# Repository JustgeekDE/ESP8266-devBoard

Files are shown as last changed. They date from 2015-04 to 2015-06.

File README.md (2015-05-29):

# ESP 8266 Dev board
A couple of different layouts for development boards for the ESP 8266 WiFi module.

## ESP8266-dev
This board is intended as a low cost, easy to build and source entry point to ESP 8266 development. After removing (or de-populating) the ESP part of the dev board, it can also be used with a different firmware as an AVR ISP programmer, SPI interface or for a variety of other uses.

However the AVR-CDC firmware is only reliable up to 4800 baud and can't reliably negotiate the 500 mA needed for the reliable operation.

## ESP8266-dev-ftdi
This is a small badge-like breakout board with onboard RGB LEDs. The aim of this board is to provide an easy to use playground for the V-01 version of the ESP 8266 module, while still being able to be used as a general interface board.

The chip reset of the ESP8266 is only released after the 500mA has been successfully negotiated.

Since a FT230X is used, the UART interface is lacking the DTR signal.

## Errata
- The USB socket on v0.1 of the FTDI board is a bit to far away from the board edge
- The RX and TX Leds on v0.1 of the FTDI board should be tied to VCC instead of GND

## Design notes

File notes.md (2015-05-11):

- Uart to slow
- multiple connections for IO
- ISP default powered
- Reverse uart
- Check current draw on power

check IO

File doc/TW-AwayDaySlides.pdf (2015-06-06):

EU AWAY DAY 2015

# IOT AND THE ESP8266

Building your own thing of the internet in 45 minutes

## raspberry pi arduino spark.io zigBee light blue bean

… ?

## THE ESP8266

## Lots of processing power • raspberry pi • beaglebone

## Connected anywhere • particle electron

Very low power •light blue bean •JeeNode

Easy to start • particle core • particle photon

## THE ESP8266

## Network

- 802.11 b / g / n
- built-in TCP / IP stack

## CPU

- 32 bit
- 80 MHz
- 64 KB instruction RAM
- 96 KB data RAM
- 64KB boot ROM

## Input / Output

- 2-11 GPIO
- ADC / SPI / PWM / SDIO / UART / I2C

# Let’s build something

( http://esp8266.ru/esplorer/#download )

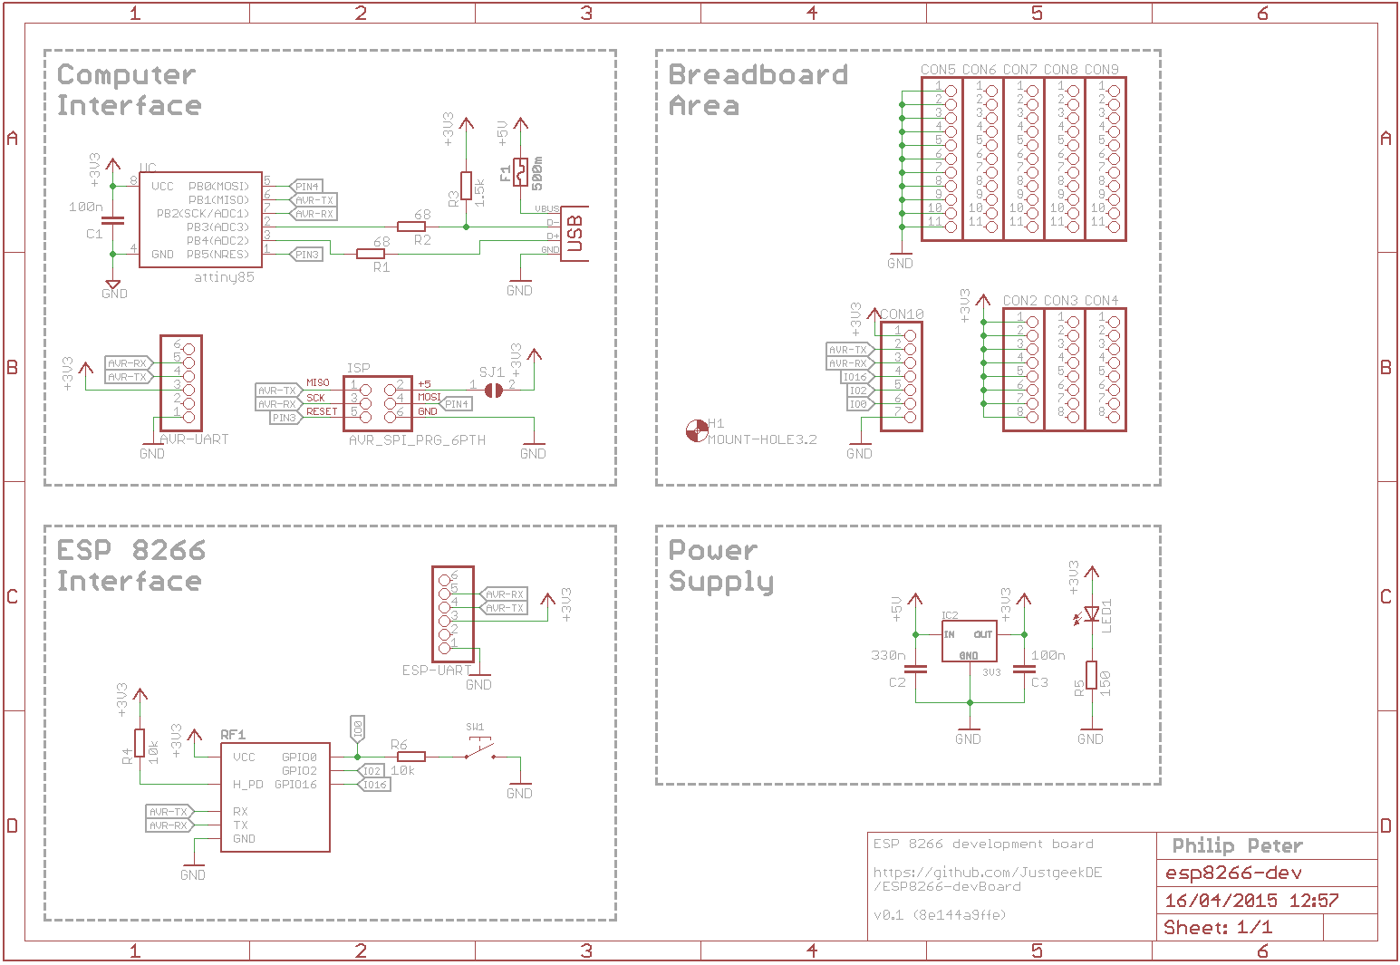
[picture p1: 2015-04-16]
doc/esp8266-dev-schematic.png

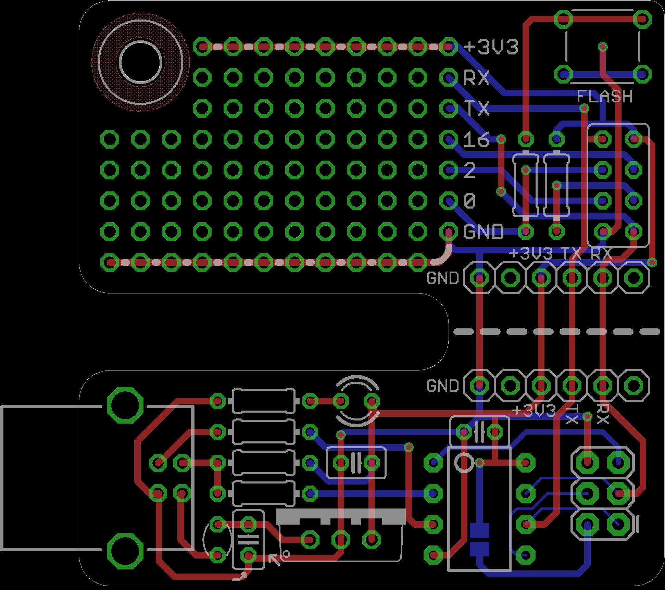
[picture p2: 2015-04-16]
doc/esp8266-dev-board-both.png

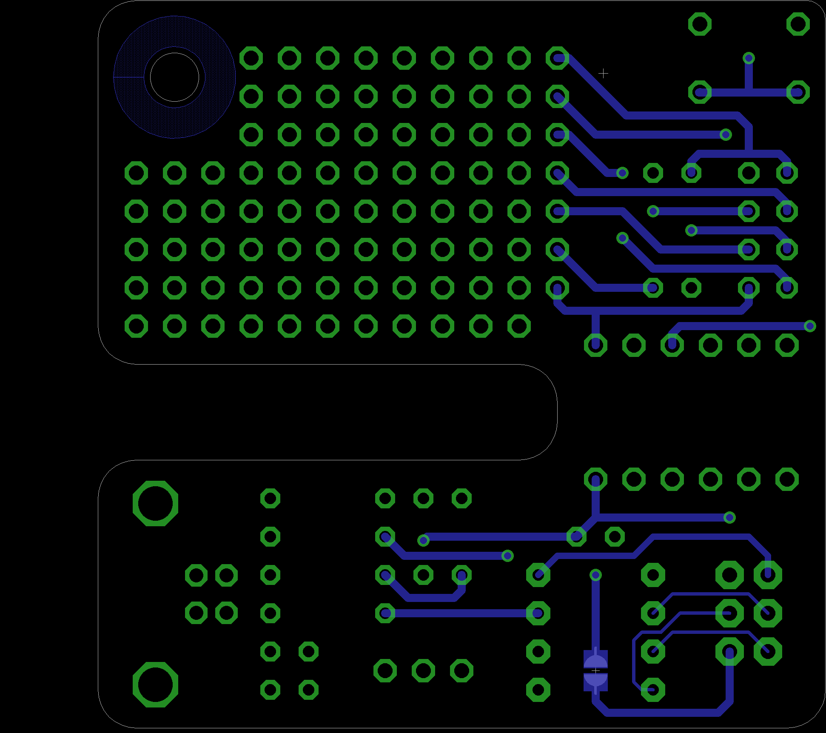
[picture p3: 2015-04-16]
doc/esp8266-dev-board-bottom.png

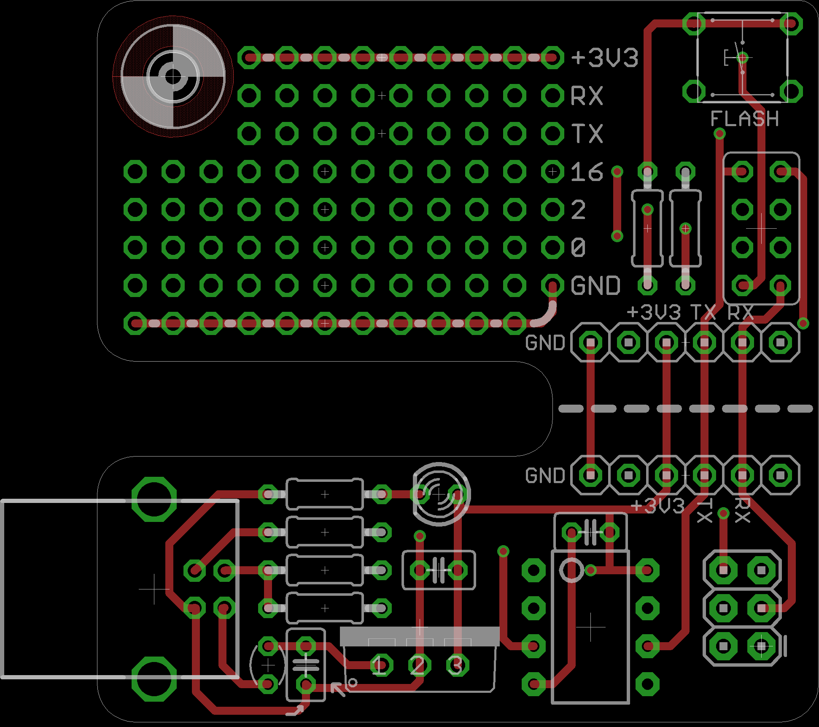
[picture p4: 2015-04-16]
doc/esp8266-dev-board-top.png

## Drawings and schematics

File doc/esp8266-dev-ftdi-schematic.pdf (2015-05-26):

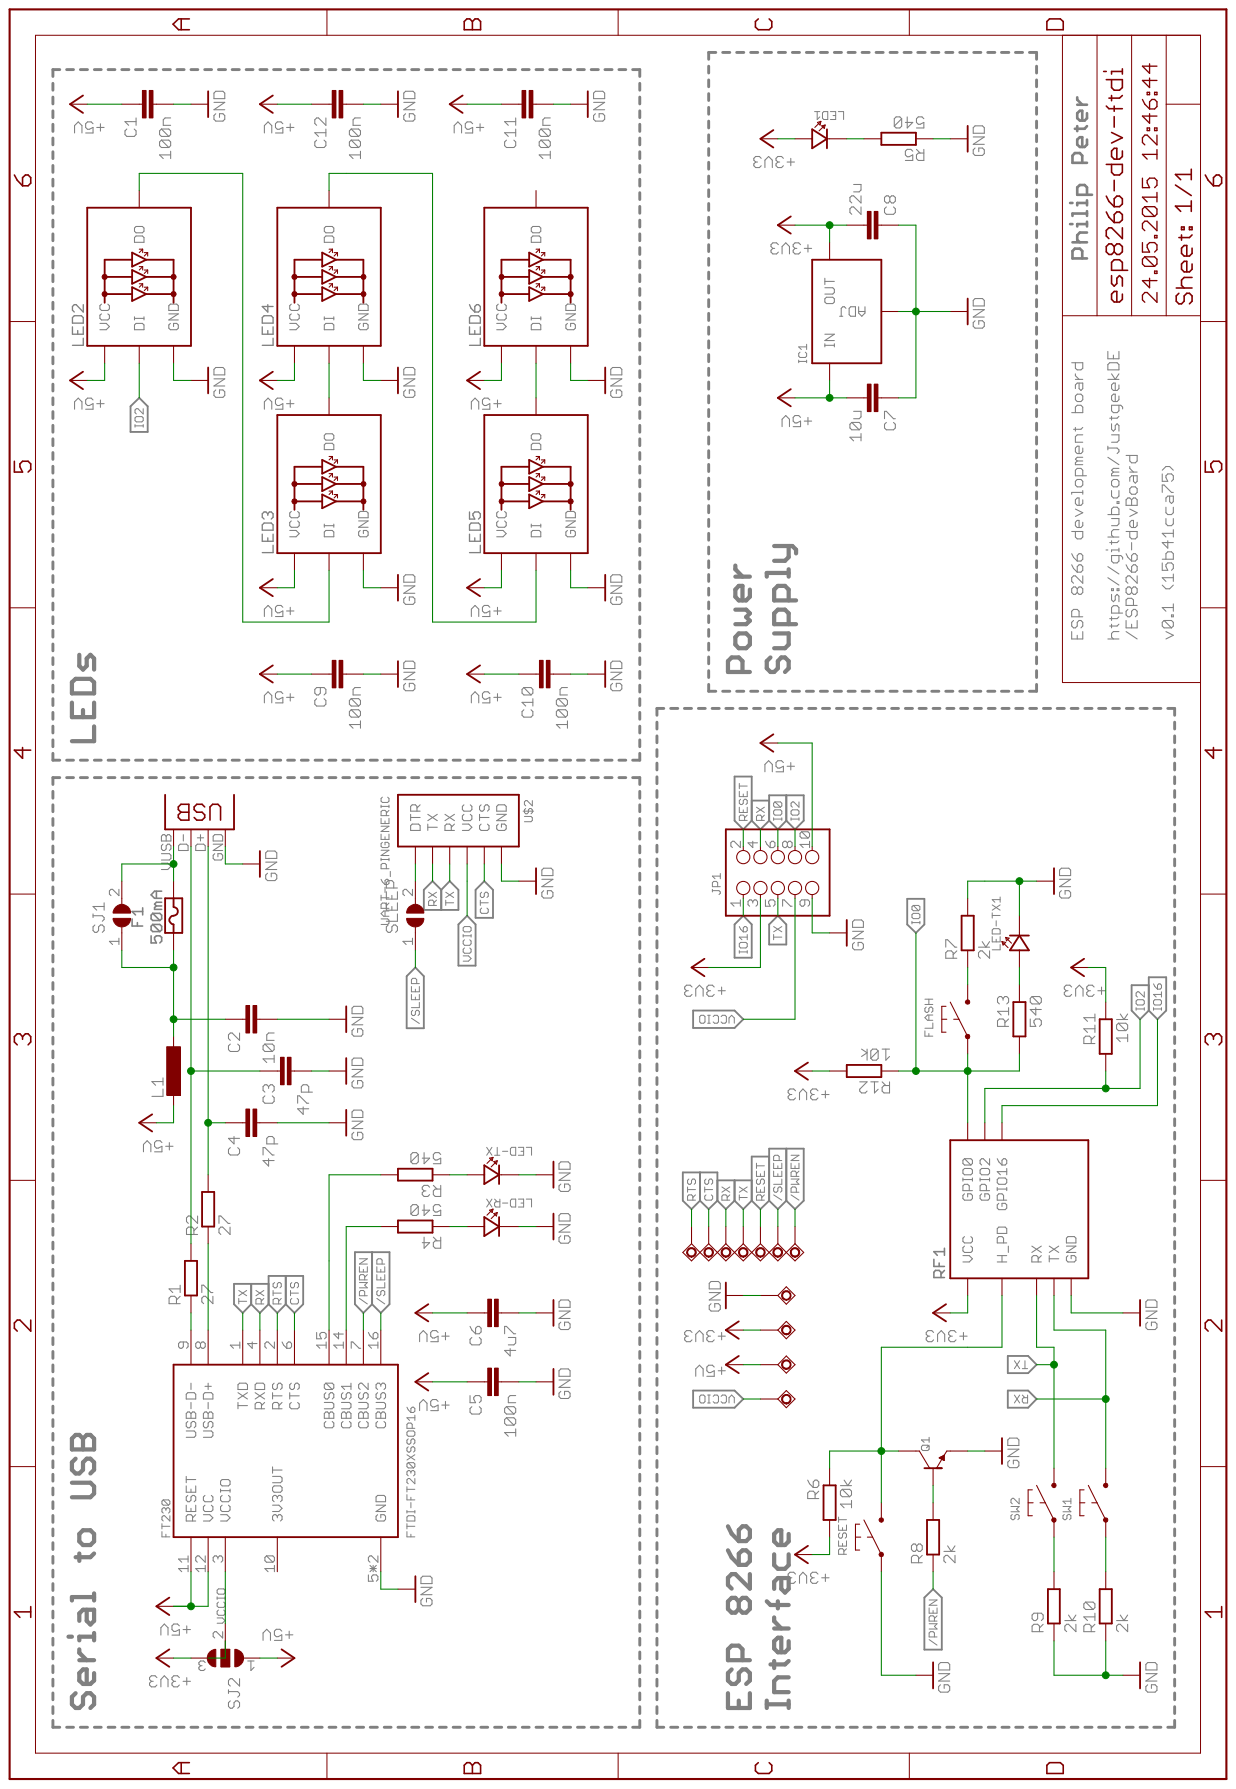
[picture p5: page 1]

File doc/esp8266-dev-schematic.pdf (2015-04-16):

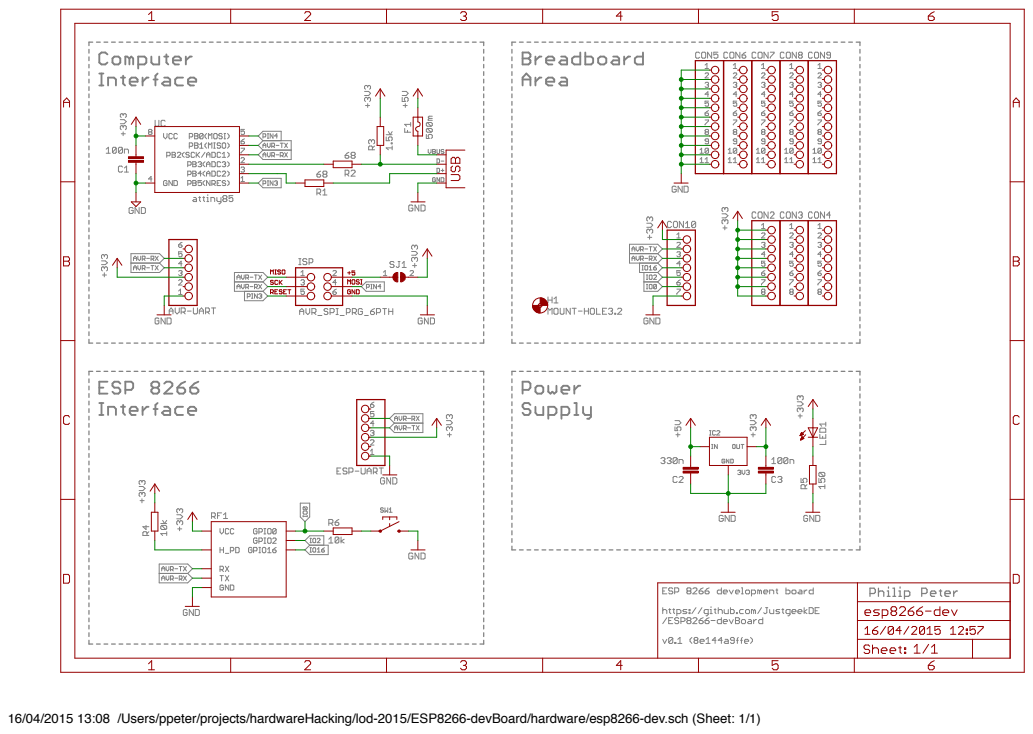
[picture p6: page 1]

16/04/2015 13:08 /Users/ppeter/projects/hardwareHacking/lod-2015/ESP8266-devBoard/hardware/esp8266-dev.sch (Sheet: 1/1)

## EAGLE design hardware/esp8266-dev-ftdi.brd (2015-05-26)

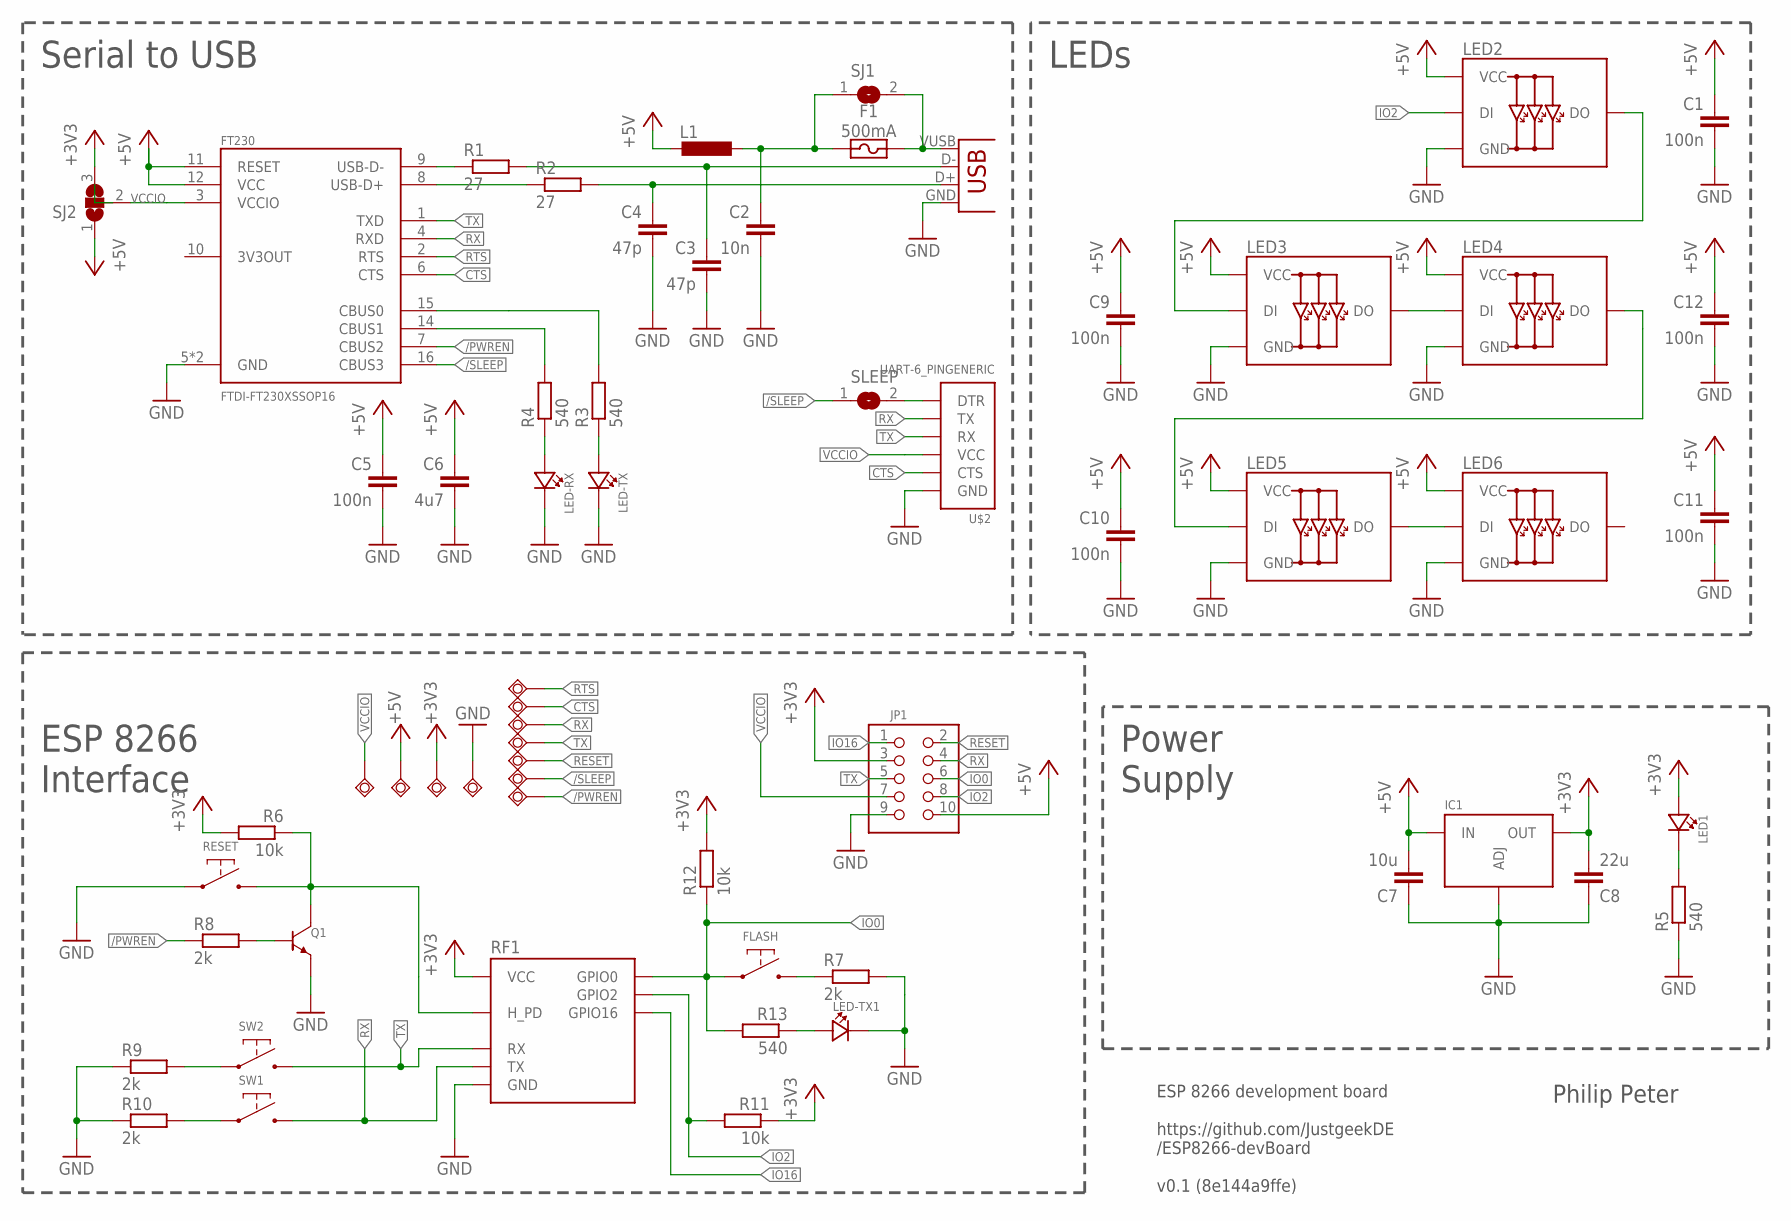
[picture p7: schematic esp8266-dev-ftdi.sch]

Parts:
3V3, 5V: TPSQTP15R; TP15R
C1, C5, C9, C10, C11, C12: 100n; C0805
C2: 10n; C0805
C3, C4: 47p; C0805
C6: 4u7; C0805
C7: 10u; C0805
C8: 22u; C0805
CON1: USBMICRO-NO_CENTER-LONG_PADS; USB-MICRO-SMD-NO_CENTER-LONG_PADS
CTS: TPSQTP15R; TP15R
F1: 500mA; SMD-FUSE-0805
FLASH: SWITCH-DEFAULT_OFF-DEFAULT; SWITCH-GENERIC-4_PIN
FT230: FTDI-FT230XSSOP16; SSOP-16-FTDI
GND: TPSQTP15R; TP15R
IC1: REGULATOR-LM317-SOT223; SOT223
JP1: GENERIC-2X5; PINHEADER-100MIL-2X5-NOSILK
L1: 875-MI0805K601R-10; R0805
LED1: LED0805; CHIPLED_0805
LED2, LED3, LED4, LED5, LED6: WS2812B; CHIP-5050-4_PIN
LED-RX: LED0805; CHIPLED_0805
LED-TX, LED-TX1: LED0805; CHIPLED_0805
PEN: TPSQTP15R; TP15R
Q1: TRANSISTOR-NPN-GENERIC-SOT23-BEC; SOT23
R1, R2: 27; R0805
R3, R4, R5, R13: 540; R0805
R6, R11, R12: 10k; R0805
R7, R8, R9, R10: 2k; R0805
RES: TPSQTP15R; TP15R
RESET: SWITCH-DEFAULT_OFF-2PIN; SWITCH-GENERIC-2_PIN
RF1: ESP2866-ESP-01THT; ESP8266-ESP-01
RTS: TPSQTP15R; TP15R
RX: TPSQTP15R; TP15R
SJ1: SJ
SJ2: SJ2W; SJ_2
SLE: TPSQTP15R; TP15R
SLEEP: SJ
SW1, SW2: SWITCH-DEFAULT_OFF-2PIN; SWITCH-GENERIC-2_PIN
TX: TPSQTP15R; TP15R
U$2: UART-6_PINGENERIC; PINHEADER-100MIL-1X6
VCC: TPSQTP15R; TP15R

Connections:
+3V3: 3V3.TP, C8.2, IC1.2 (OUT), IC1.4 (OUT), JP1.3, LED1.A, R6.2, R11.1, R12.2, RF1.VCC, SJ2.3
+5V: 5V.TP, C1.1, C5.1, C6.1, C7.2, C9.1, C10.1, C11.1, C12.1, FT230.11 (RESET), FT230.12 (VCC), IC1.3 (IN), JP1.10, L1.2, LED2.P$1 (VCC), LED3.P$1 (VCC), LED4.P$1 (VCC), LED5.P$1 (VCC), LED6.P$1 (VCC), SJ2.1
/PWREN: FT230.7 (CBUS2), PEN.TP, R8.1
/SLEEP: FT230.16 (CBUS3), SLE.TP, SLEEP.1
CTS: CTS.TP, FT230.6 (CTS), U$2.2 (CTS)
GND: C1.2, C2.2, C3.2, C4.2, C5.2, C6.2, C7.1, C8.1, C9.2, C10.2, C11.2, C12.2, CON1.GND, FT230.5 (GND), FT230.13 (GND), GND.TP, IC1.1 (ADJ), JP1.9, LED2.P$3 (GND), LED3.P$3 (GND), LED4.P$3 (GND), LED5.P$3 (GND), LED6.P$3 (GND), LED-RX.C, LED-TX.C, LED-TX1.C, Q1.P$2 (EMITTER), R5.1, R7.2, R9.1, R10.1, RESET.P$1, RF1.GND, U$2.1 (GND)
IO0: FLASH.P$1, FLASH.P$2, JP1.6, R12.1, R13.2, RF1.GPIO0
IO2: JP1.8, LED2.P$4 (DI), R11.2, RF1.GPIO2
IO16: JP1.1, RF1.GPIO16
unnamed: Q1.P$1 (BASE), R8.2
unnamed: C2.1, F1.1, L1.1, SJ1.1
unnamed: LED-TX.A, R3.1
unnamed: C3.1, CON1.D-, R1.2
unnamed: FT230.9 (USB-D-), R1.1
unnamed: FT230.8 (USB-D+), R2.1
unnamed: C4.1, CON1.D+, R2.2
unnamed: LED-RX.A, R4.1
unnamed: LED1.C, R5.2
unnamed: SLEEP.2, U$2.6 (DTR)
unnamed: FLASH.P$3, FLASH.P$4, R7.1
unnamed: LED2.P$2 (DO), LED3.P$4 (DI)
unnamed: FT230.15 (CBUS0), R3.2
unnamed: FT230.14 (CBUS1), R4.2
unnamed: LED3.P$2 (DO), LED4.P$4 (DI)
unnamed: LED4.P$2 (DO), LED5.P$4 (DI)
unnamed: LED5.P$2 (DO), LED6.P$4 (DI)
unnamed: CON1.VUSB (VBUS), F1.2, SJ1.2
unnamed: R9.2, SW2.P$1
unnamed: R10.2, SW1.P$1
unnamed: LED-TX1.A, R13.1
RESET: JP1.2, Q1.P$3 (COLLECTOR), R6.1, RES.TP, RESET.P$2, RF1.H_PD
RTS: FT230.2 (RTS), RTS.TP
RX: FT230.4 (RXD), JP1.4, RF1.TX, RX.TP, SW1.P$2, U$2.5 (TX)
TX: FT230.1 (TXD), JP1.5, RF1.RX, SW2.P$2, TX.TP, U$2.4 (RX)
VCCIO: FT230.3 (VCCIO), JP1.7, SJ2.2, U$2.3 (VCC), VCC.TP

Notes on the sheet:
ESP 8266 Interface
Power Supply
Philip Peter
ESP 8266 development board https://github.com/JustgeekDE /ESP8266-devBoard v0.1 (8e144a9ffe)
LEDs
Serial to USB

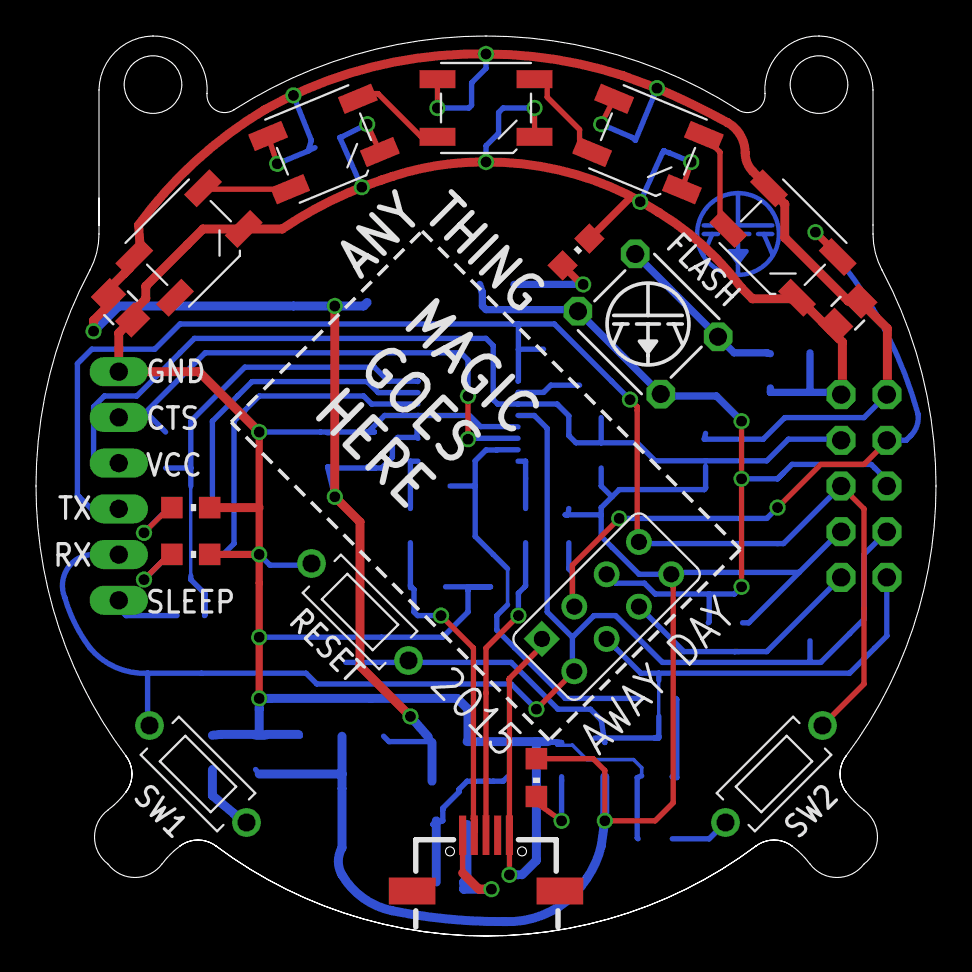
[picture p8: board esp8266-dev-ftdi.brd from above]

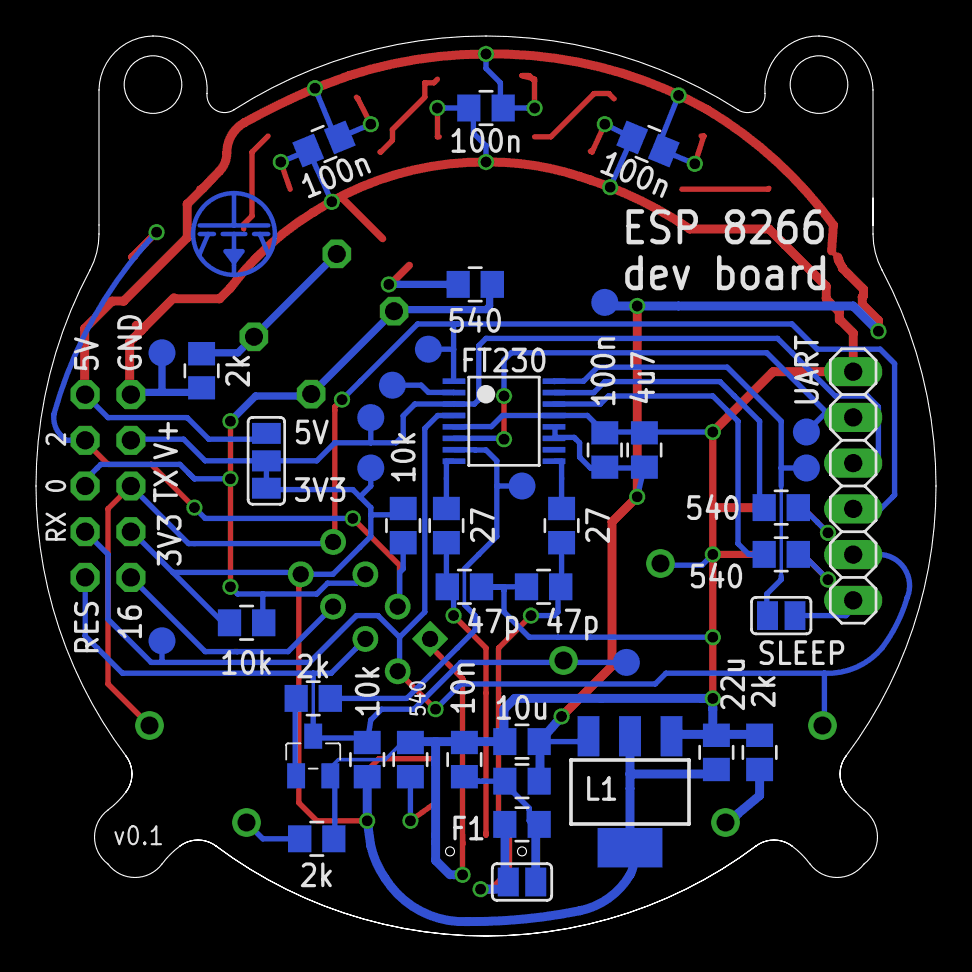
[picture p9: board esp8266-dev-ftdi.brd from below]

Board: 2 copper layers, 50.0 x 50.0 mm, 63 parts (45 on the bottom side), 35 nets.

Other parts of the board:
U$1: LOGO-JUSTGEEK-XS-PAD
U$3: LOGO-JUSTGEEK-XS

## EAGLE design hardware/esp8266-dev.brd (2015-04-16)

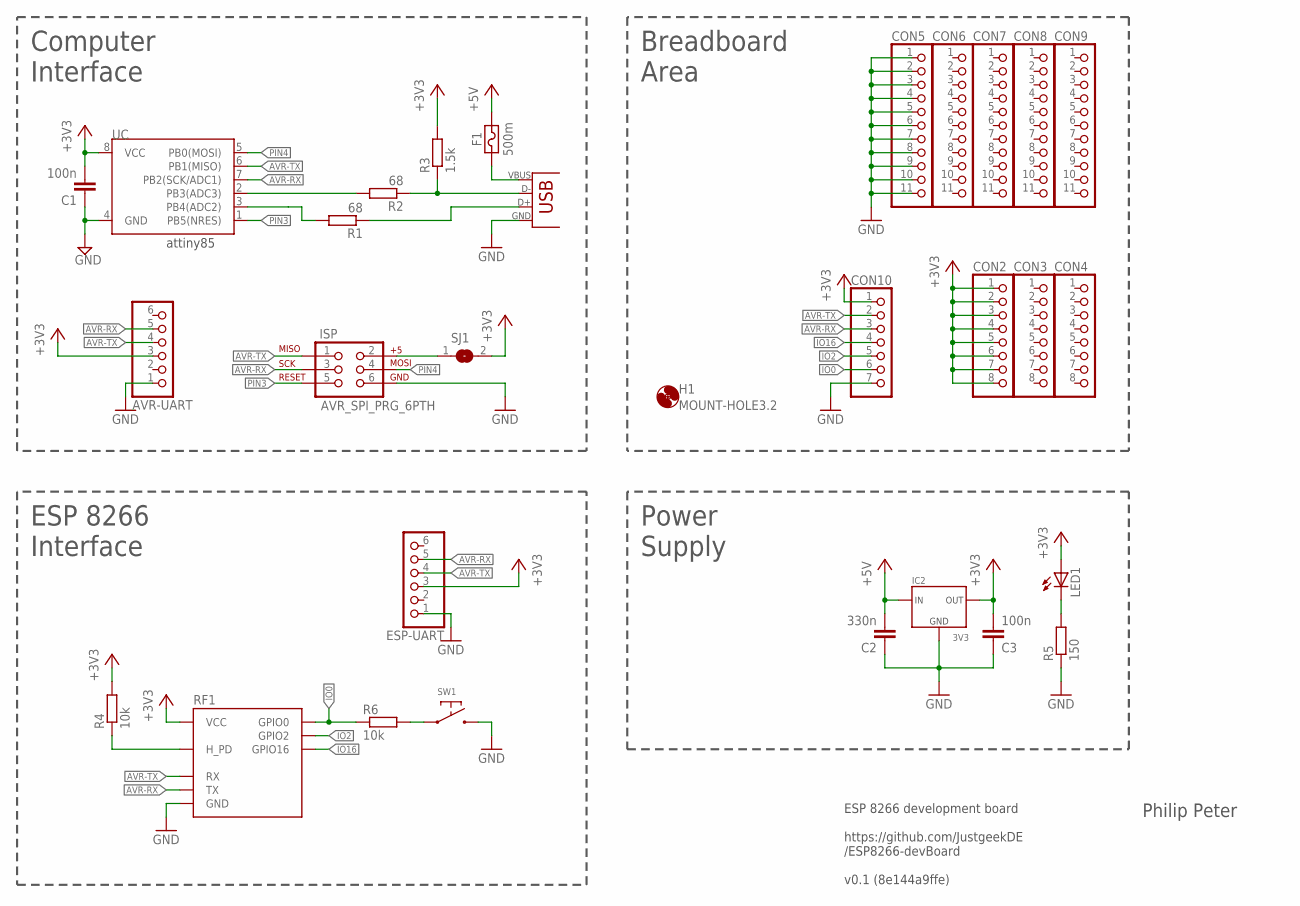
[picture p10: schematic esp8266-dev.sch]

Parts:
AVR-UART: GENERIC-1X6STANDARD; PINHEADER-100MIL-1X6
C1, C3: 100n; C025-025X050
C2: 330n; C025-025X050
CON1: USBB-SOCKET; PN61729-S
CON2, CON3, CON4: GENERIC-1X8NOSILK; PINHEADER-100MIL-1X8-NOSILK
CON5, CON6, CON7, CON8, CON9: GENERIC-1X11NOSILK; PINHEADER-100MIL-1X11-NOSILK
CON10: GENERIC-1X7NOSILK; PINHEADER-100MIL-1X7-NOSILK
ESP-UART: GENERIC-1X6STANDARD; PINHEADER-100MIL-1X6
F1: 500m; FUSE-THT-100-MIL
H1: MOUNT-HOLE3.2; 3,2
IC2: 3V3; TO220V
ISP: AVR_SPI_PRG_6PTH; 2X3
LED1: LED3MM
R1, R2: 68; 0204/7
R3: 1.5k; 0204/7
R4, R6: 10k; 0204/7
R5: 150; 0204/7
RF1: ESP2866-ESP-01THT-NOSILK; ESP8266-ESP-01-NOSILK
SJ1: SJ
SW1: SWITCH-DEFAULT_OFF-DEFAULT; SWITCH-GENERIC-4_PIN
UC: ATTINY85; DIP08

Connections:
+3V3: AVR-UART.3, C1.2, C3.2, CON2.1, CON2.2, CON2.3, CON2.4, CON2.5, CON2.6, CON2.7, CON2.8, CON10.1, ESP-UART.3, IC2.3 (OUT), LED1.A, R3.2, R4.2, RF1.VCC, SJ1.2, UC.8 (VCC)
+5V: C2.2, F1.P$2, IC2.1 (IN)
AVR-RX: AVR-UART.5, CON10.3, ESP-UART.5, ISP.3, RF1.TX, UC.7 (PB2(SCK/ADC1))
AVR-TX: AVR-UART.4, CON10.2, ESP-UART.4, ISP.1, RF1.RX, UC.6 (PB1(MISO))
D+: CON1.3 (D+), R1.1
D-: CON1.2 (D-), R2.1, R3.1
GND: AVR-UART.1, C1.1, C2.1, C3.1, CON1.4 (GND), CON5.1, CON5.2, CON5.3, CON5.4, CON5.5, CON5.6, CON5.7, CON5.8, CON5.9, CON5.10, CON5.11, CON10.7, ESP-UART.1, IC2.2 (GND), ISP.6, R5.1, RF1.GND, SW1.P$3, SW1.P$4, UC.4 (GND)
IO0: CON10.6, R6.1, RF1.GPIO0
IO2: CON10.5, RF1.GPIO2
IO16: CON10.4, RF1.GPIO16
unnamed: R2.2, UC.2 (PB3(ADC3))
unnamed: R1.2, UC.3 (PB4(ADC2))
unnamed: LED1.K (C), R5.2
unnamed: CON1.1 (VBUS), F1.P$1
unnamed: R4.1, RF1.H_PD
unnamed: R6.2, SW1.P$1, SW1.P$2
PIN3: ISP.5, UC.1 (PB5(NRES))
PIN4: ISP.4, UC.5 (PB0(MOSI))
VCC_HEADER: ISP.2, SJ1.1

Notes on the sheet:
attiny85
Computer Interface
ESP 8266 Interface
Breadboard Area
Power Supply
Philip Peter
ESP 8266 development board https://github.com/JustgeekDE /ESP8266-devBoard v0.1 (8e144a9ffe)

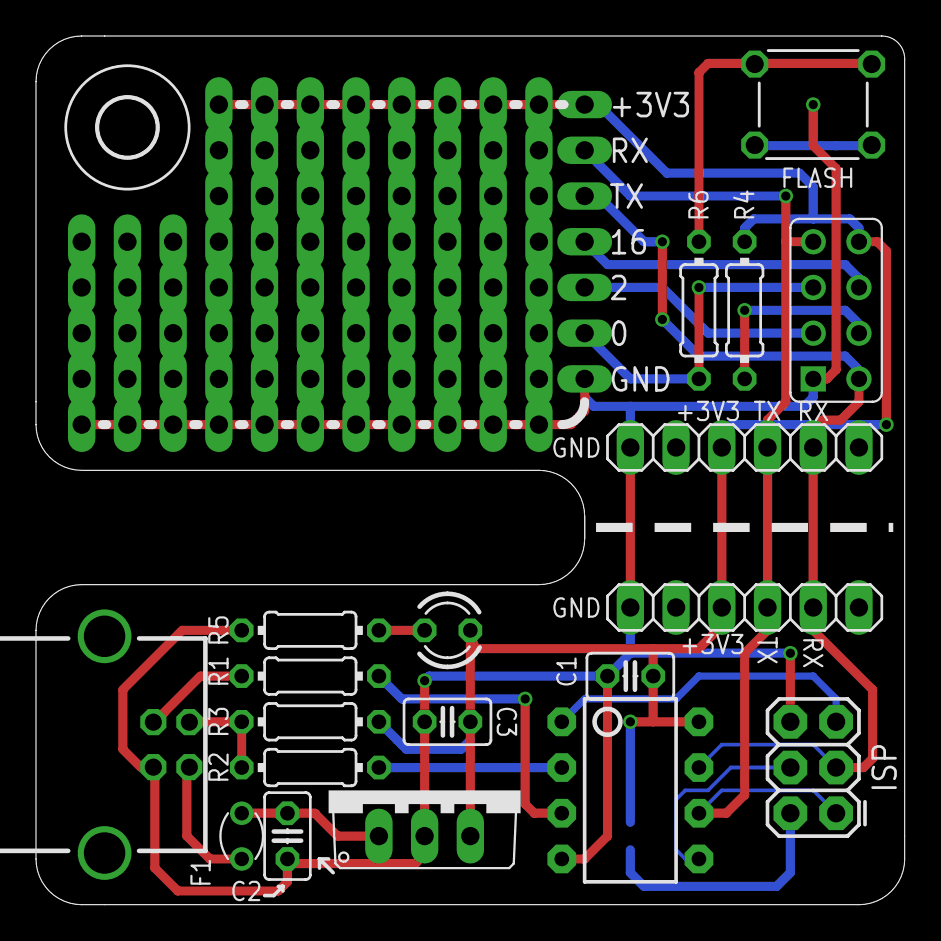
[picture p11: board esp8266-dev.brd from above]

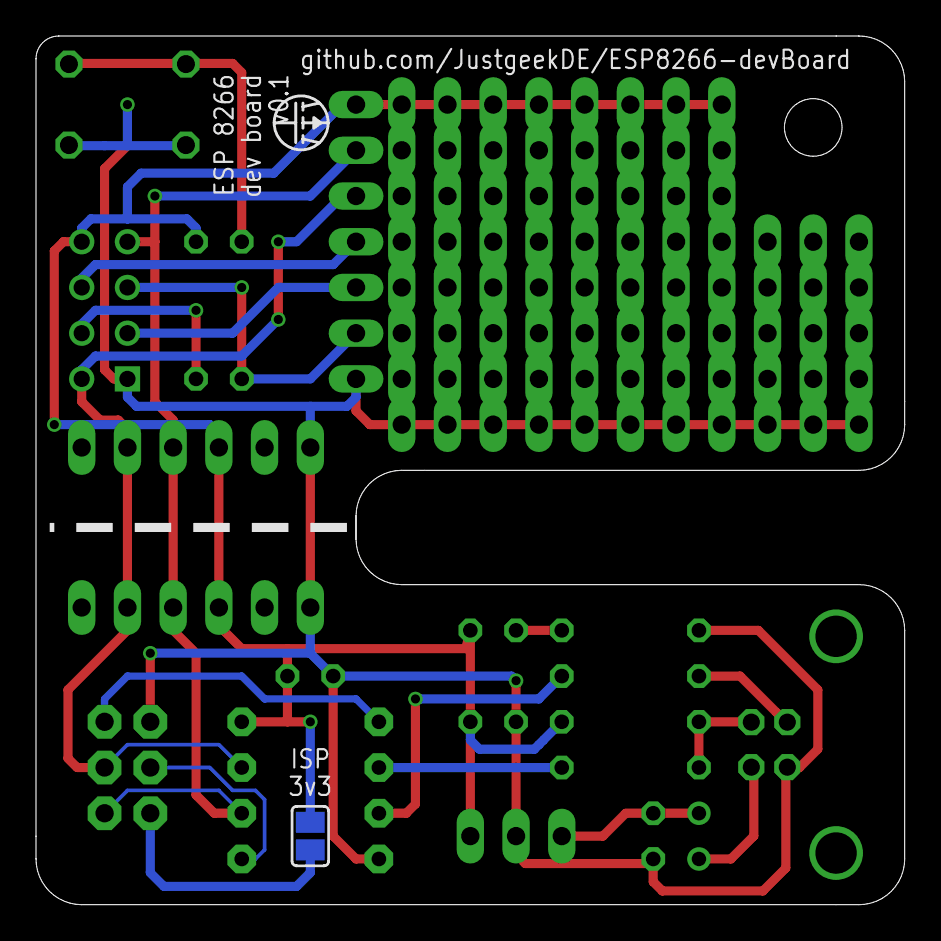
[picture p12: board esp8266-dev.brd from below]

Board: 2 copper layers, 48.3 x 48.3 mm, 31 parts (2 on the bottom side), 19 nets.

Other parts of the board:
U$3: LOGO-JUSTGEEK-XXXS

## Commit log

2015-04-01 Initial checkin
    [esp8266-dev.sch]
2015-04-03 Added notes, to keep track of todos
2015-04-03 generic little wire conversion complete
    [esp8266-dev.brd, esp8266-dev.sch]
2015-04-04 Added ESP sub board with proto area
    [esp8266-dev.brd, esp8266-dev.sch]
2015-04-04 changed regulator to 500m suitable version and fuse to smaller footprint
    [esp8266-dev.brd, esp8266-dev.sch]
2015-04-04 basic lazyout done, cleaning up silkscreen
    [esp8266-dev.brd, esp8266-dev.sch]
2015-04-04 first acceptable layout, off to review
    [esp8266-dev.brd]
2015-04-05 Added more silkscreen
    [esp8266-dev.brd]
2015-04-05 Further cleanup
    [esp8266-dev.brd, esp8266-dev.sch]
2015-04-05 Also ignoring gerber files now
2015-04-05 Fixed silkscreen on board
    [esp8266-dev.brd]
2015-04-16 Cleaned up schematic
    [esp8266-dev.brd, esp8266-dev.sch]
2015-04-16 Added some documentation
    [esp8266-dev.brd]
2015-05-11 Working on FTDI based board
    [esp8266-dev-ftdi.brd, esp8266-dev-ftdi.sch]
2015-05-19 Changed to FTDI module instead of discrete components
    [esp8266-dev-ftdi.brd, esp8266-dev-ftdi.sch]
2015-05-19 Changed board dimensions
    [esp8266-dev-ftdi.brd]
2015-05-20 Revert "Changed board dimensions"
    This reverts commit 250896ee29173e178886add8db11c26ec19ca707.
    [esp8266-dev-ftdi.brd]
2015-05-20 Revert "Changed to FTDI module instead of discrete components"
    This reverts commit a00f7f1f84a57c5e7a19d78f77a78fc68ade4bc8.
    [esp8266-dev-ftdi.brd, esp8266-dev-ftdi.sch]
2015-05-20 Added LEDs
    [esp8266-dev-ftdi.brd, esp8266-dev-ftdi.sch]
2015-05-20 Updated todos
    [esp8266-dev-ftdi.sch]
2015-05-21 added todo
    [esp8266-dev-ftdi.sch]
2015-05-21 added result of snap to board to gitignore
2015-05-21 schematic mostly done
    [esp8266-dev-ftdi.brd, esp8266-dev-ftdi.sch]
2015-05-21 new USB connector with longer pads
    [esp8266-dev-ftdi.brd, esp8266-dev-ftdi.sch]
2015-05-21 starting layout
    [esp8266-dev-ftdi.brd, esp8266-dev-ftdi.sch]
2015-05-21 board outline and orga
    [esp8266-dev-ftdi.brd, esp8266-dev-ftdi.sch]
2015-05-21 LED power
    [esp8266-dev-ftdi.brd, esp8266-dev-ftdi.sch]
2015-05-21 Everything routed
    [esp8266-dev-ftdi.brd, esp8266-dev-ftdi.sch]
2015-05-22 Layout done
    [esp8266-dev-ftdi.brd, esp8266-dev-ftdi.sch]
2015-05-22 added test pads
    [esp8266-dev-ftdi.brd, esp8266-dev-ftdi.sch]
2015-05-22 minor cleanup
    [esp8266-dev-ftdi.brd]
2015-05-22 adjusted dimensions to make mounting holes more robust
    [esp8266-dev-ftdi.brd]
2015-05-22 silkscreen adjustments
    [esp8266-dev-ftdi.brd]
2015-05-22 added led to gpio2
    [esp8266-dev-ftdi.brd, esp8266-dev-ftdi.sch]
2015-05-22 basic layoutfor added components
    [esp8266-dev-ftdi.brd, esp8266-dev-ftdi.sch]
2015-05-22 routed new components in layout
    [esp8266-dev-ftdi.brd]
2015-05-22 fixed silkscreen for new components
    [esp8266-dev-ftdi.brd]
2015-05-22 added notches for rubberbands to dimension
    [esp8266-dev-ftdi.brd]
2015-05-22 added decoupling caps for leds
    [esp8266-dev-ftdi.brd, esp8266-dev-ftdi.sch]
2015-05-22 changed bottom values to place layer
    [esp8266-dev-ftdi.brd]
2015-05-22 Increasing distance between pads and signals
    [esp8266-dev-ftdi.brd]
2015-05-24 cleanup schematict
    [esp8266-dev-ftdi.sch]
2015-05-28 Added test header for provisioning
    [testHeader.sch]
2015-05-29 Basic color wheel as example for loops, conditions and WS2812b handling
